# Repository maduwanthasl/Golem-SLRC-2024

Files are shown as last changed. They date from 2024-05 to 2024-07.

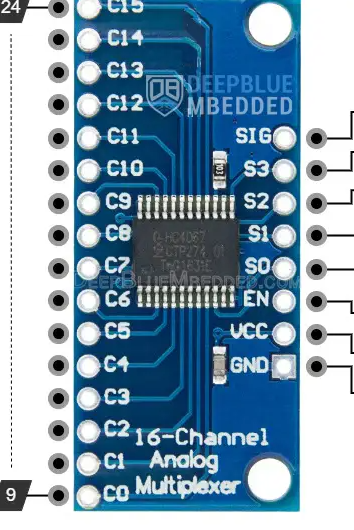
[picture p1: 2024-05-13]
SLRC shield/DOCS/Screenshot 2024-04-01 222949.png

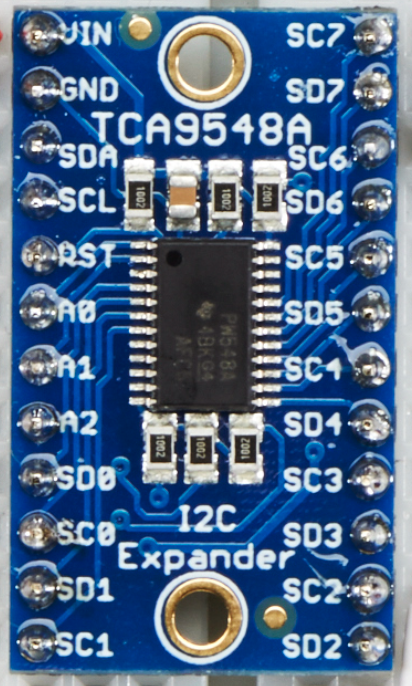
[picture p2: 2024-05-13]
SLRC shield/DOCS/Screenshot 2024-04-01 223036.png

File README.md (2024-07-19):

# Golem - SLRC 2024

Welcome to the Golem-SLRC-2024 repository! This project showcases my participation in the Sri Lanka Robotic Challenge (SLRC) 2024, organized by the Electronic Club at the University of Moratuwa. I participated as an individual team member and successfully completed the elimination round, securing a place in the final round. This repository contains the final code, design files, and documentation for my robot, Golem.

task

## Project Overview

Golem is a line-following robot designed to navigate complex paths and perform various tasks autonomously. The robot was built using an Arduino Mega board, various sensors, motor drivers, and custom-designed components. A notable feature of Golem is its robotic arm, which I designed and 3D printed using my Imagineer 3D printer. This document provides a detailed overview of the project's development, including the design, implementation, and functionality of Golem.

## Table of Contents
- [Project Overview](#project-overview)
- [Hardware Components](#hardware-components)
- [Software Components](#software-components)
- [Robot Design](#robot-design)
- [Functionality](#functionality)
- [Code Segments](#code-segments)
- [Photos](#photos)
- [Acknowledgements](#acknowledgements)

## Hardware Components

- Arduino Mega Board
- 14 IR Sensors Array
- L298N Motor Driver
- 12V LiPo Battery
- Buck Converters (LM2596)
- TOF Sensor (Time of Flight)
- OLED Display
- Rotary Encoder
- TCS34725 Color Sensor Module
- Ultrasonic Sensor
- MG995 Servo Motor
- Hobby Servo Motor
- Custom 3D Printed Parts (using Imagineer 3D Printer)
- Acrylic Sheets for Chassis

## Software Components

The software for Golem was developed using Arduino IDE, and the code is organized into several sub-functions to handle different tasks:

- Forward Line Following
- Reverse Line Following
- IR Sensor Calibration
- EEPROM Read/Write
- TOF Distance Measurement
- Color Detection
- Object Detection
- Robotic Arm Control

## Robot Design

In the initial stage, I constructed the robot chassis using acrylic sheets and purchased various components. The design process involved categorizing all functions into sub-functions and developing them within a specified time frame.

### Sub-Tasks

1. **Forward Line Following**: Using a 14 IR sensor array to follow lines.
2. **Distance Measurement**: Adding a TOF sensor to measure distance.
3. **Function Control**: Using an OLED display and rotary encoder to control functions.
4. **IR Sensor Calibration**: Developing calibration code for the IR arrays.
5. **Reverse Line Following**: Adding a reverse IR array for reverse functions and junction detection.
6. **EEPROM Storage**: Implementing EEPROM read/write functions for calibration values.
7. **Color Detection**: Using a TCS34725 color sensor module for junction color detection.
8. **Object Detection**: Adding an ultrasonic sensor for object detection and differentiation between cuboid and cylinder.
9. **Robotic Arm**: Constructing a simple 2-DOF robotic arm to pick up metal boxes.

## Functionality

## Software Components

The software for Golem was developed in a modular approach, where each functionality was divided into sub-functions and implemented step-by-step. The key functionalities include:

### 1. Forward Line Following using 14 IR Sensors

I used 14 IR sensors to develop the line-following task. The IR sensors detect the path, and the robot adjusts its movement accordingly using the L298N motor driver. The 12V LiPo battery provides the necessary power, and buck converters (LM2596) ensure stable voltage for the components.

#### Sensor calibration
```cpp
#include "calibrate_sensor.h"

/*-----------------------------------------------------------------------------------------------------------
----------------------------------------------SENSOR CALIBRATION---------------------------------------------
-----------------------------------------------------------------------------------------------------------*/

// Function to save threshold values to EEPROM
void saveThresholdToEEPROM() {
  int address = 0; // Starting EEPROM address to write the data

  // Write threshold values to EEPROM
  for (int i = 0; i < numSensors; i++) {
    EEPROM.put(address, threshold[i]); // Write threshold value to EEPROM
    address += sizeof(int); // Increment address for next threshold value
  }

}

// Function to read threshold values from EEPROM
void readThresholdFromEEPROM() {
  int address = 0; // Starting EEPROM address to read the data

  // Read threshold values from EEPROM
  for (int i = 0; i < numSensors ; i++) {
    EEPROM.get(address, threshold[i]); // Read threshold value from EEPROM
    address += sizeof(int); // Increment address for next threshold value
  }
}

void calibrateSensors() {
  Serial.println("Calibrating sensors...");
  
  // Initialize minValues and maxValues arrays
  for (int i = 0; i < numSensors; i++) {
    minValues[i] = 1023; // Initialize with maximum possible value
    maxValues[i] = 0; // Initialize with minimum possible value
  }

  // Move motors to calibrate sensors
  for (int i = 0; i < 12000; i++) { // Adjust the loop count and motor speeds as needed
    analogWrite(leftmotor_pwm,105);
    analogWrite(rightmotor_pwm,105);
    digitalWrite(leftForward,HIGH);
    digitalWrite(rightBackward,HIGH);
    for (int sensorIndex = 0; sensorIndex < numSensors; sensorIndex++) {
      int sensorValue = analogRead(sensorPins[sensorIndex]);
      minValues[sensorIndex] = min(minValues[sensorIndex], sensorValue);
      maxValues[sensorIndex] = max(maxValues[sensorIndex], sensorValue);
    }
  }

  // Stop motors
  analogWrite(leftmotor_pwm,0);
  analogWrite(rightmotor_pwm,0);
  stop_bot();

  // Calculate thresholds
  for (int i = 0; i < numSensors; i++) {
    threshold[i] = (minValues[i] + maxValues[i]) / 2;
  }

  // // Print thresholds
  // Serial.println("Sensor thresholds:");
  // for (int i = 0; i < numSensors; i++) {
  //   Serial.print("Sensor ");
  //   Serial.print(i + 1);
  //   Serial.print(": ");
  //   Serial.println(threshold[i]);
  // }
  // Serial.println("Calibration complete.");

}

/*------------------------------------------------------------------------------------------------------------
--------------------------------------------------------------------------------------------------------------
------------------------------------------------------------------------------------------------------------*/

// Function to save threshold values to EEPROM for reverse sensors
void saveThresholdToEEPROMreverse() {
  int address = 0; // Starting EEPROM address to write the data

  // Write threshold values to EEPROM
  for (int i = 0; i < numReverseSensors; i++) {
    EEPROM.put(address, reverseThreshold[i]); // Write threshold value to EEPROM
    address += sizeof(int); // Increment address for next threshold value
  }
}

// Function to read threshold values from EEPROM for reverse sensors
void readThresholdFromEEPROMreverse() {
  int address = 0; // Starting EEPROM address to read the data

  // Read threshold values from EEPROM
  for (int i = 0; i < numReverseSensors ; i++) {
    EEPROM.get(address, reverseThreshold[i]); // Read threshold value from EEPROM
    address += sizeof(int); // Increment address for next threshold value
  }
}

void calibrateReverseSensors() {
  Serial.println("Calibrating reverse sensors...");
  
  // Initialize minValues and maxValues arrays
  for (int i = 0; i < numReverseSensors; i++) {
    reverseMinValues[i] = 1023; // Initialize with maximum possible value
    reverseMaxValues[i] = 0; // Initialize with minimum possible value
  }

  // Move motors to calibrate sensors
  for (int i = 0; i < 12000; i++) { // Adjust the loop count and motor speeds as needed
    analogWrite(leftmotor_pwm, 105);
    analogWrite(rightmotor_pwm, 105);
    digitalWrite(leftBackward, HIGH); // Assuming reverse array needs to move backward
    digitalWrite(rightForward, HIGH); // Assuming reverse array needs to move backward
    for (int sensorIndex = 0; sensorIndex < numReverseSensors; sensorIndex++) {
      // Select the channel on the multiplexer
      selectChannel(sensorIndex);

      // Read the sensor value from the multiplexer
      int sensorValue = analogRead(reverseSensorPins[sensorIndex]);

      // Update min and max values
      reverseMinValues[sensorIndex] = min(reverseMinValues[sensorIndex], sensorValue);
      reverseMaxValues[sensorIndex] = max(reverseMaxValues[sensorIndex], sensorValue);
    }
  }

  // Stop motors
  analogWrite(leftmotor_pwm, 0);
  analogWrite(rightmotor_pwm, 0);
  stop_bot();

  // Calculate thresholds
  for (int i = 0; i < numReverseSensors; i++) {
    reverseThreshold[i] = (reverseMinValues[i] + reverseMaxValues[i]) / 2;
  }

  Serial.println("Reverse sensor thresholds:");
  for (int i = 0; i < numReverseSensors; i++) {
    Serial.print("Sensor ");
    Serial.print(i + 1);
    Serial.print(": ");
    Serial.println(reverseThreshold[i]);
  }
  Serial.println("Reverse Calibration complete.");
}
```

```cpp
void read_sensor_values()
{
  readThresholdFromEEPROM();
  // White == 1 & Black == 0 left - , right +
  for (int sensorIndex = 0; sensorIndex < numSensors; sensorIndex++) {
    sensorValues[sensorIndex] = analogRead(sensorPins[sensorIndex]);
    if (sensorValues[sensorIndex] > threshold[sensorIndex]) {
        sensorValues[sensorIndex] = 0;
    } else {
        sensorValues[sensorIndex] = 1;
    }
  }

  int expectedValues[][numSensors] = {
    // Add your expected values here
  };

  int errorValues[] = {
    // Add your error values here
  };

  bool conditionMet = false;
  int defaultErrorValue = 0;

  for (int condIndex = 0; condIndex < sizeof(expectedValues) / sizeof(expectedValues[0]); condIndex++) {
    conditionMet = true;
    for (int sensorIndex = 0; sensorIndex < numSensors; sensorIndex++) {
      if (expectedValues[condIndex][sensorIndex] != -1 && sensorValues[sensorIndex] != expectedValues[condIndex][sensorIndex]) {
        conditionMet = false;
        break;
      }
    }
    if (conditionMet) {
      error = errorValues[condIndex];
      if (condIndex >= sizeof(errorValues) / sizeof(errorValues[0]) - 13) {
        motor_pos = 0; motor_pos2 = 0;
        count_encoder(0.45);
        junction_count++;
        motor_pos = 0; motor_pos2 = 0;
        Serial.println(junction_count);
      }
      break;
    }
  }

  if (!conditionMet) {
    error = defaultErrorValue;
  }
}
```

### 2. TOF Sensor Integration for Distance Measurement

A Time of Flight (TOF) sensor was added to measure the distance accurately. This helps the robot navigate and avoid obstacles.

```cpp
#include "measure_distance_tof.h"

static Adafruit_VL53L0X lox = Adafruit_VL53L0X();

void measure_distance_tof_setup() {
  Serial.begin(9600);

  // Wait until serial port opens for native USB devices
  while (!Serial) {
    delay(1);
  }

  Serial.println("Adafruit VL53L0X test");
  if (!lox.begin()) {
    Serial.println(F("Failed to boot VL53L0X"));
    while(1);
  }
  // Power 
  Serial.println(F("VL53L0X API Simple Ranging example\n\n"));
}

void measure_distance_tof_loop(int Samples) {
  VL53L0X_RangingMeasurementData_t measure;
  unsigned long totalDistance = 0; // Variable to store the total distance
  int numSamples = Samples ; // Number of samples to average

  for (int i = 0; i < numSamples; i++) {
    lox.rangingTest(&measure, false); // Perform distance measurement
    if (measure.RangeStatus != 4) {  // Phase failures have incorrect data
      totalDistance += measure.RangeMilliMeter; // Add the distance measurement to the total
    }
    delay(50); // Wait a short time between measurements
  }

  // Compute the average distance
  distance_tof = totalDistance / numSamples;

  Serial.print("Average Distance (mm): ");
  Serial.println(distance_tof);
  return;

}
```

### 3. OLED Display and Rotary Encoder for Control

An OLED display was added to provide real-time information about the robot's status. The rotary encoder allows for easy navigation through different functions and settings on the display, making the robot more user-friendly.

### 4. IR Array Calibration

Calibration code for the IR arrays was developed to ensure accurate line following. Here is a sample of the calibration code:

### 5. Reverse Function and Junction Detection
A reverse IR array was added to enable the robot to move backward and detect junctions. Calibration code was also implemented for the reverse sensors. The calibrated values are stored in the EEPROM for quick access.

### 6. EEPROM Read and Write
I developed code to read and write calibration values to the EEPROM. This ensures that the robot retains its calibration settings even after power cycles.

### 7. Color Detection using TCS34725
A TCS34725 color sensor module was mounted below the robot to detect color junctions on the path. This sensor helps the robot identify different colored markers on the track.

### 8. Ultrasonic Sensor for Object Detection
An ultrasonic sensor was used to detect objects within a circle. The sensor measures the distance and helps identify whether the object is a cuboid or a cylinder based on the variance in the measurements.

### 9. Robotic Arm with 2 DOF
I designed a simple robotic arm with two degrees of freedom (DOF) to pick up objects. The arm uses an MG995 servo motor and a hobby servo motor. The arm design was created using CAD software and 3D printed using my Imagineer 3D printer.

## Code Segments
Here are some key code segments used in the project:

### IR Sensor Calibration
```cpp
void calibrateSensors() {
    // Calibration logic
}
```

### EEPROM Read and Write
```cpp
void saveThresholdToEEPROM() {
    // Code to save calibration values to EEPROM
}

void readThresholdFromEEPROM() {
    // Code to read calibration values from EEPROM
}
```
### Color Detection
```cpp
void detectColor() {
    // Code to detect colors using TCS34725 sensor
}
```
### Ultrasonic Object Detection
```cpp

void detectObject() {
    // Code to detect objects using ultrasonic sensor
}
```
## Photos
Robot Photos: Link to Photos
Task Photos: Link to Photos
Elimination Round Photos: Link to Photos

## Acknowledgements
I would like to thank the Electronic Club at the University of Moratuwa for organizing the Sri Lanka Robotic Challenge (SLRC) 2024. Special thanks to my mentors and peers for their support and guidance throughout the project.

Contact
For any questions or collaborations, feel free to reach out to me at [Your Email].

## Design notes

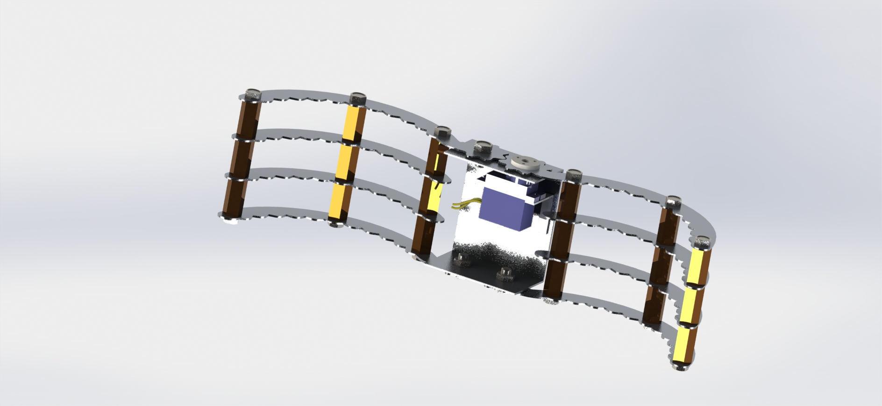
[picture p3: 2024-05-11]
3d printed parts/robot-claw-robot-gripper-gripper-manipulator-mechanical-claw-arm-1.snapshot.3/f3.JPG

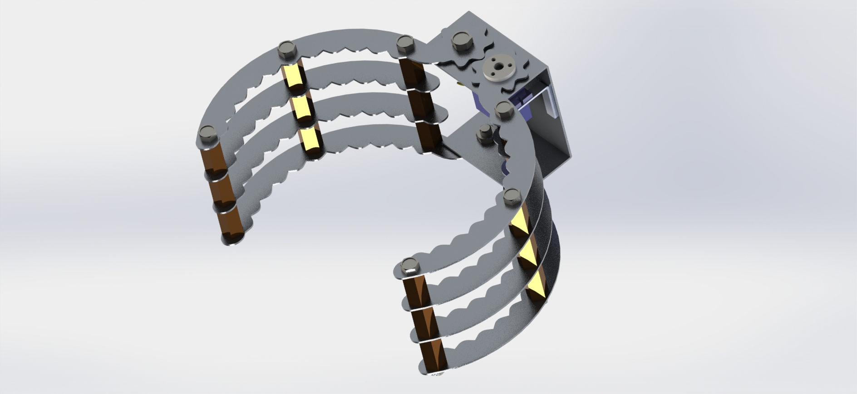
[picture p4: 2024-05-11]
3d printed parts/robot-claw-robot-gripper-gripper-manipulator-mechanical-claw-arm-1.snapshot.3/f2.JPG

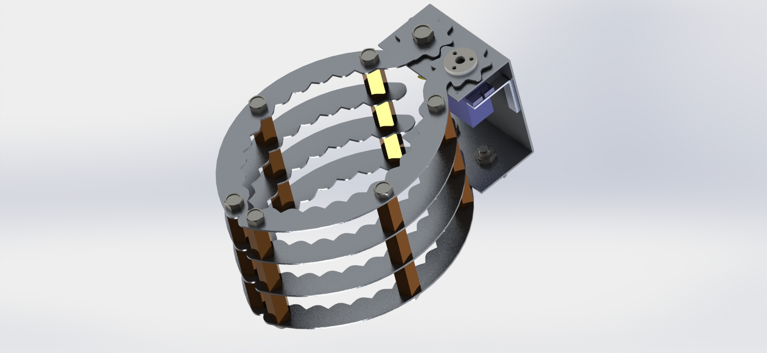
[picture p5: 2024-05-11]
3d printed parts/robot-claw-robot-gripper-gripper-manipulator-mechanical-claw-arm-1.snapshot.3/f1.JPG

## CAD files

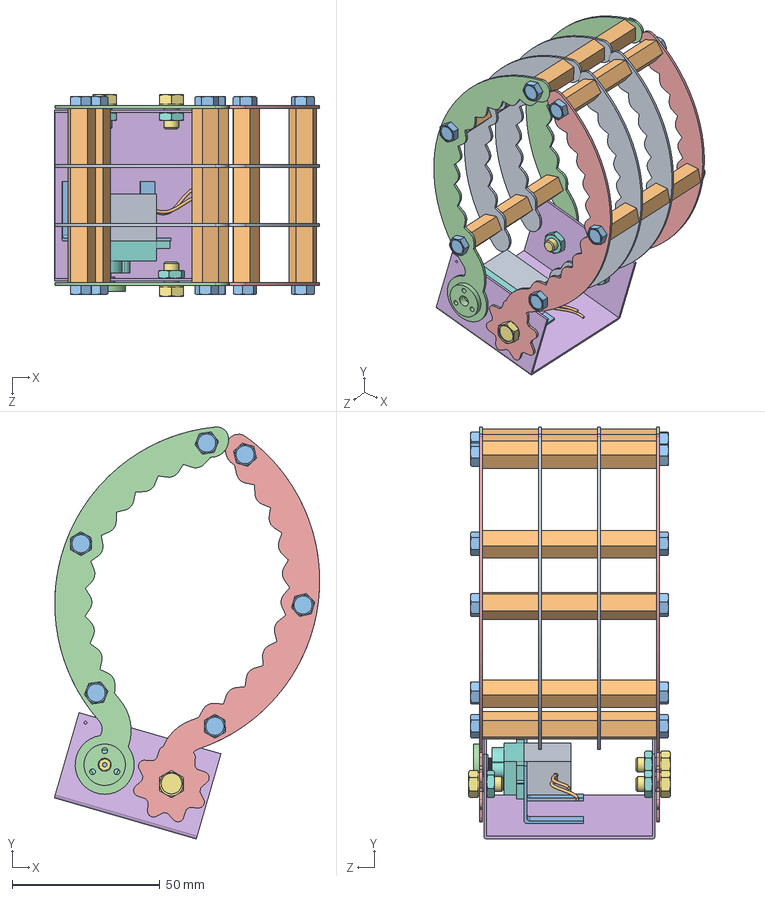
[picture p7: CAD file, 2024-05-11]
3d printed parts/robot-claw-robot-gripper-gripper-manipulator-mechanical-claw-arm-1.snapshot.3/oval-kiskac.SLDASM
89.8 x 139.4 x 68.3 mm
kiskac2 x 4
araparca x 18
hex screw_am x 12
kiskac1 x 2
kiskac1-sol x 2
U-sac
formed hex screw_am x 3
hex nut jam_am x 3
lower cover
motor
feedback potentiometer
Part6^servo motor assembley
Part7^servo motor assembley
Part8^servo motor assembley
Part10^servo motor assembley
upper cover
Part16^servo motor assembley
Part21^servo motor assembley
20x20x1kosebent x 2
dondurme-aparati

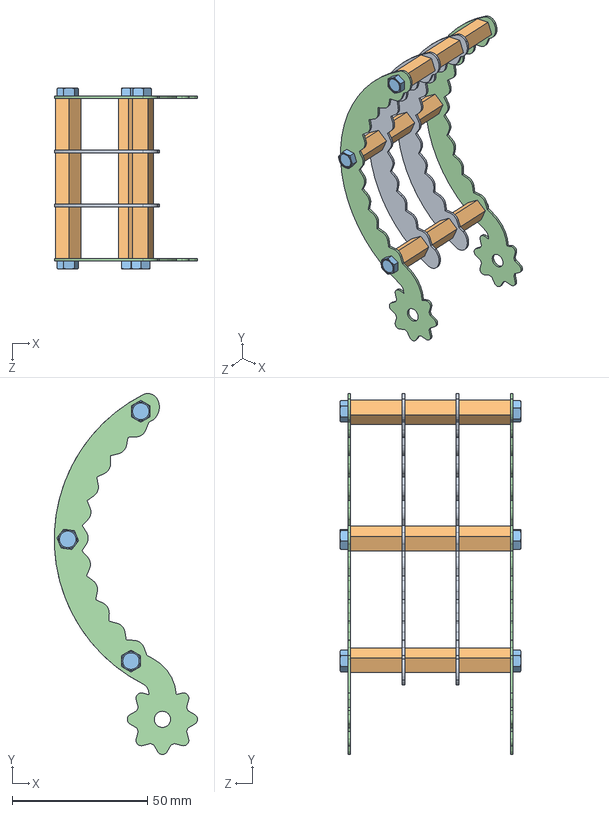
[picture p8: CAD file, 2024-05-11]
3d printed parts/robot-claw-robot-gripper-gripper-manipulator-mechanical-claw-arm-1.snapshot.3/kıskac2-montaj.SLDASM
52.9 x 133.5 x 67.0 mm
kiskac2 x 2
araparca x 9
hex screw_am x 6
kiskac1 x 2

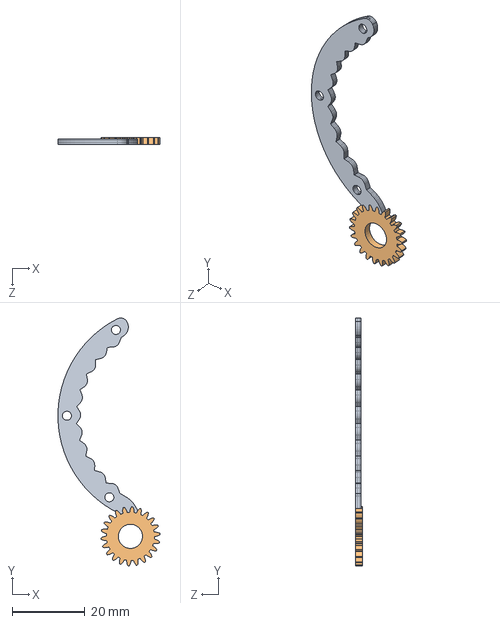
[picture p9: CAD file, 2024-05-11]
3d printed parts/robot-claw-robot-gripper-gripper-manipulator-mechanical-claw-arm-1.snapshot.3/dfsgd.SLDASM
28.1 x 68.4 x 1.82 mm
kiskac1 x 3
gear

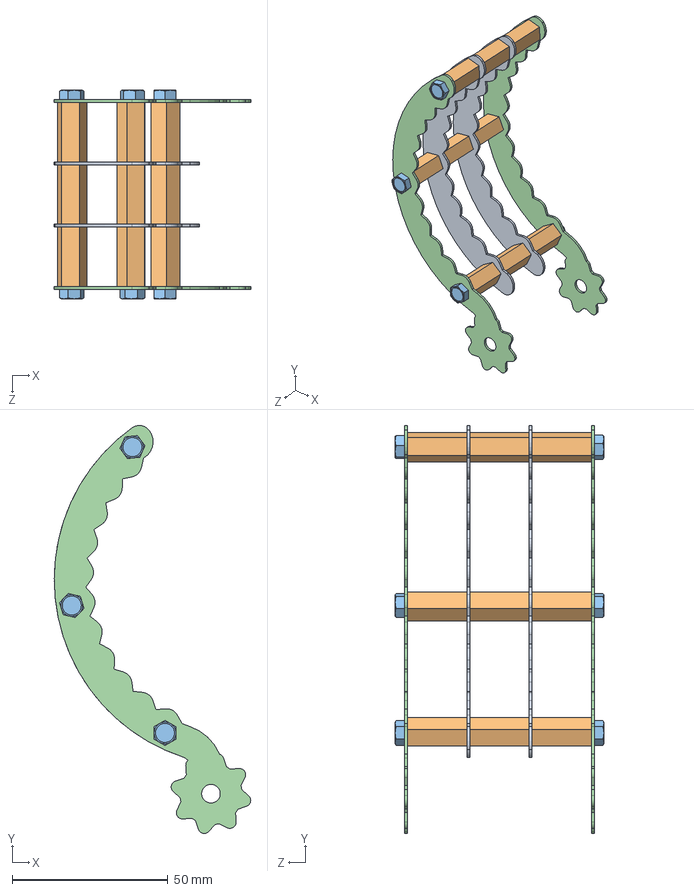
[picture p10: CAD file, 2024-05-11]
3d printed parts/robot-claw-robot-gripper-gripper-manipulator-mechanical-claw-arm-1.snapshot.3/kıskac1-montaj.SLDASM
63.1 x 131.1 x 67.0 mm
kiskac2 x 2
araparca x 9
hex screw_am x 6
kiskac1-sol x 2

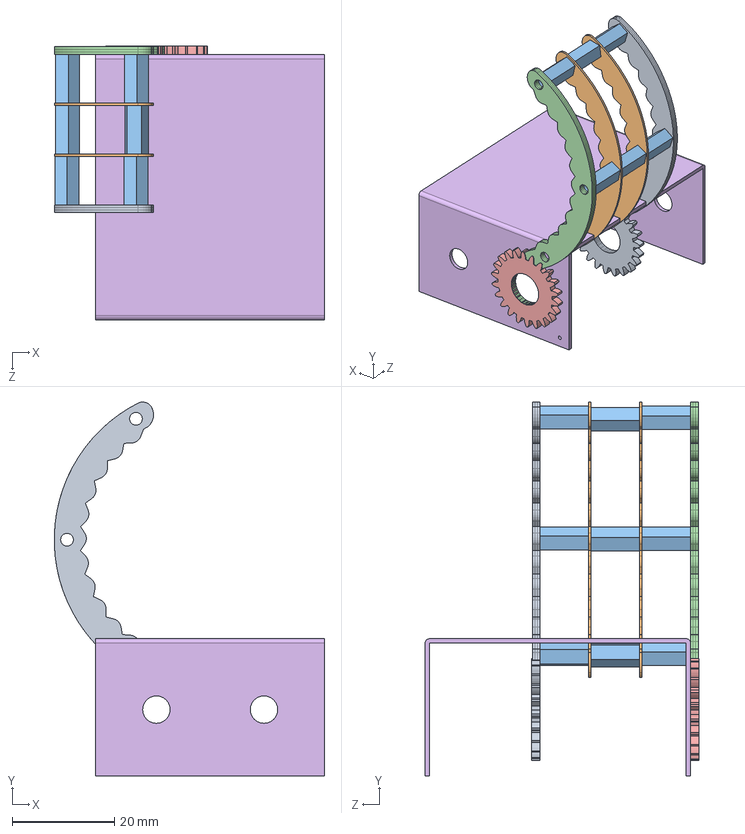
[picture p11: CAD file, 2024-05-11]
3d printed parts/robot-claw-robot-gripper-gripper-manipulator-mechanical-claw-arm-1.snapshot.3/RIGHT HAND.SLDASM
52.9 x 73.2 x 53.6 mm
handle1
kiskac2 x 2
araparca x 9
kiskac1 x 3
gear
U-sac

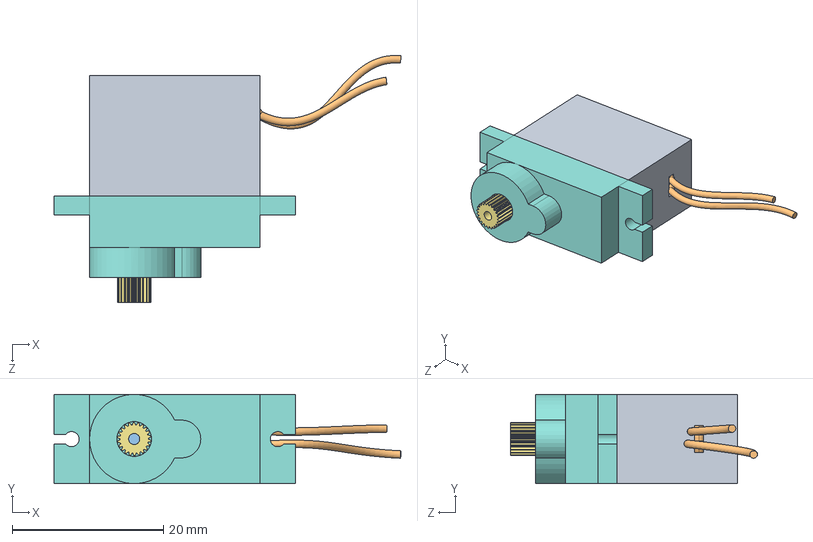
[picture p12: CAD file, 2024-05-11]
3d printed parts/robot-claw-robot-gripper-gripper-manipulator-mechanical-claw-arm-1.snapshot.3/servo-motor-montaj.SLDASM
45.9 x 11.8 x 32.7 mm
lower cover
motor
feedback potentiometer
Part6^servo motor assembley
Part7^servo motor assembley
Part8^servo motor assembley
Part10^servo motor assembley
upper cover
Part16^servo motor assembley
Part21^servo motor assembley

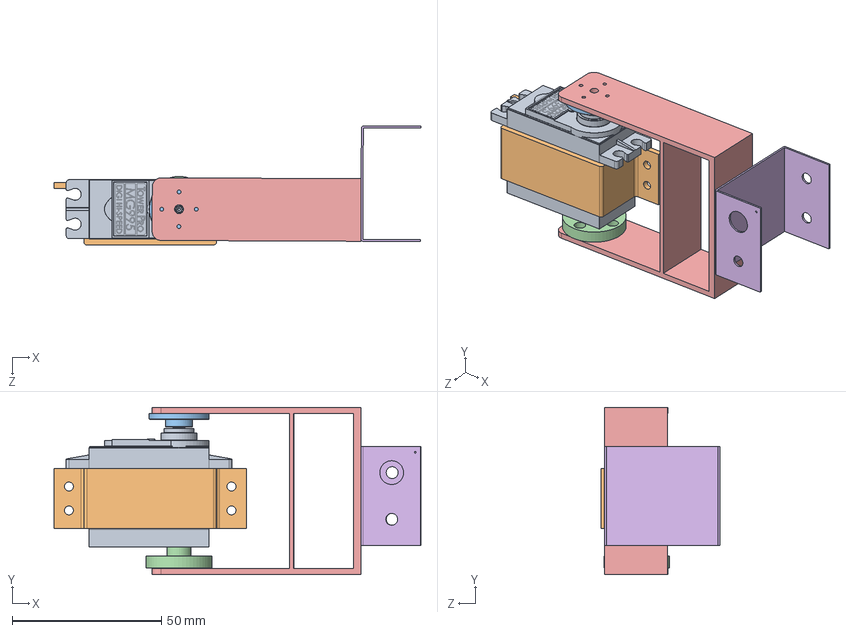
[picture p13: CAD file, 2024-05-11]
3d printed parts/Arm assemble.SLDASM
123.0 x 56.0 x 39.9 mm
Mg995
Servo holder
servo horn
hub
Arm handle
U-sac

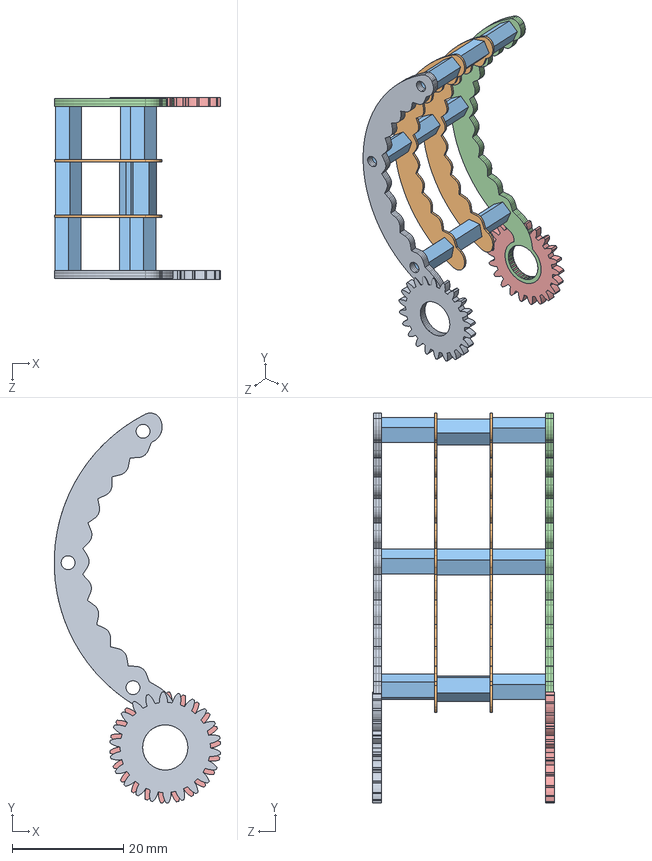
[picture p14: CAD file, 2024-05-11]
3d printed parts/robot-claw-robot-gripper-gripper-manipulator-mechanical-claw-arm-1.snapshot.3/Assem2.SLDASM
30.0 x 70.2 x 32.8 mm
handle1
kiskac2 x 2
araparca x 9
kiskac1 x 3
gear

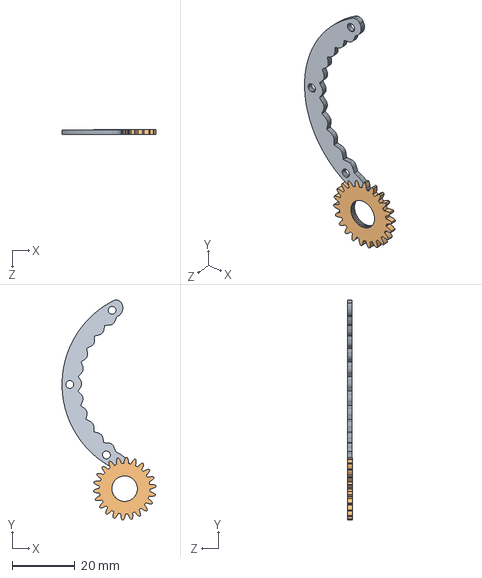
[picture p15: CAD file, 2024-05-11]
3d printed parts/robot-claw-robot-gripper-gripper-manipulator-mechanical-claw-arm-1.snapshot.3/handle 2.SLDASM
30.0 x 70.2 x 1.63 mm
kiskac1 x 3
gear

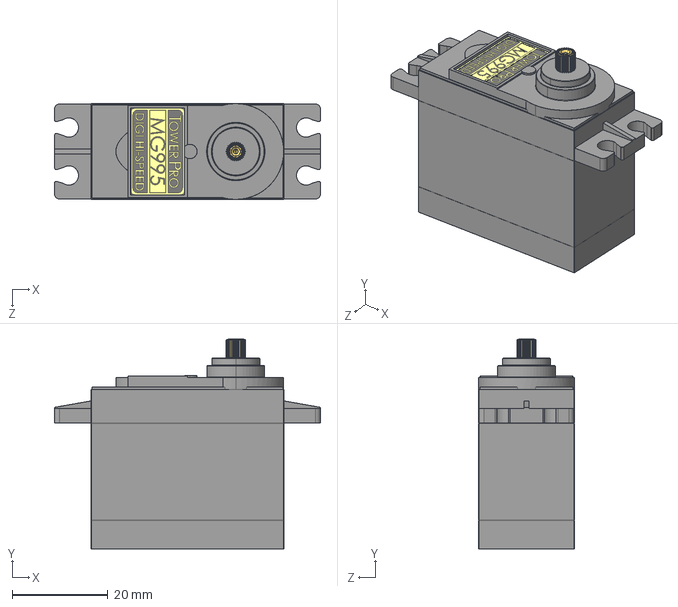
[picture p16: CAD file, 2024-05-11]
3d printed parts/mg-995-2.snapshot.2/Mg995.STEP
55.5 x 43.8 x 20.0 mm

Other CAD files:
3d printed parts/robot-claw-robot-gripper-gripper-manipulator-mechanical-claw-arm-1.snapshot.3/Part8^servo motor assembley.sldprt
3d printed parts/robot-claw-robot-gripper-gripper-manipulator-mechanical-claw-arm-1.snapshot.3/Part16^servo motor assembley.sldprt
3d printed parts/robot-claw-robot-gripper-gripper-manipulator-mechanical-claw-arm-1.snapshot.3/Part7^servo motor assembley.sldprt
3d printed parts/robot-claw-robot-gripper-gripper-manipulator-mechanical-claw-arm-1.snapshot.3/Part14^servo motor assembley.sldprt
3d printed parts/robot-claw-robot-gripper-gripper-manipulator-mechanical-claw-arm-1.snapshot.3/Part6^servo motor assembley.sldprt
3d printed parts/robot-claw-robot-gripper-gripper-manipulator-mechanical-claw-arm-1.snapshot.3/Part10^servo motor assembley.sldprt
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

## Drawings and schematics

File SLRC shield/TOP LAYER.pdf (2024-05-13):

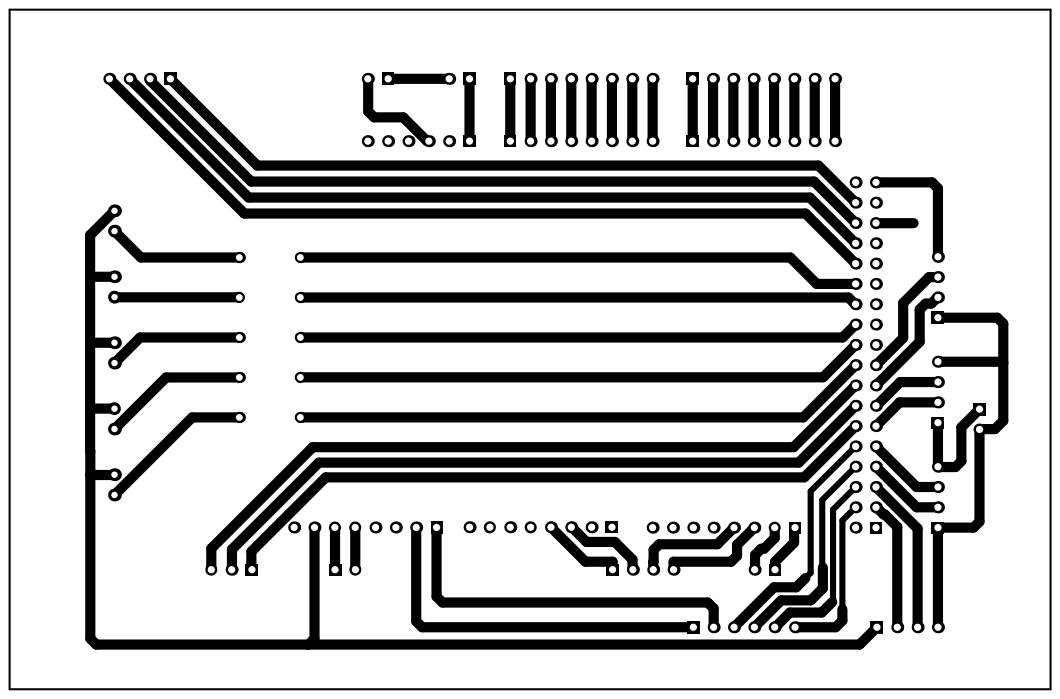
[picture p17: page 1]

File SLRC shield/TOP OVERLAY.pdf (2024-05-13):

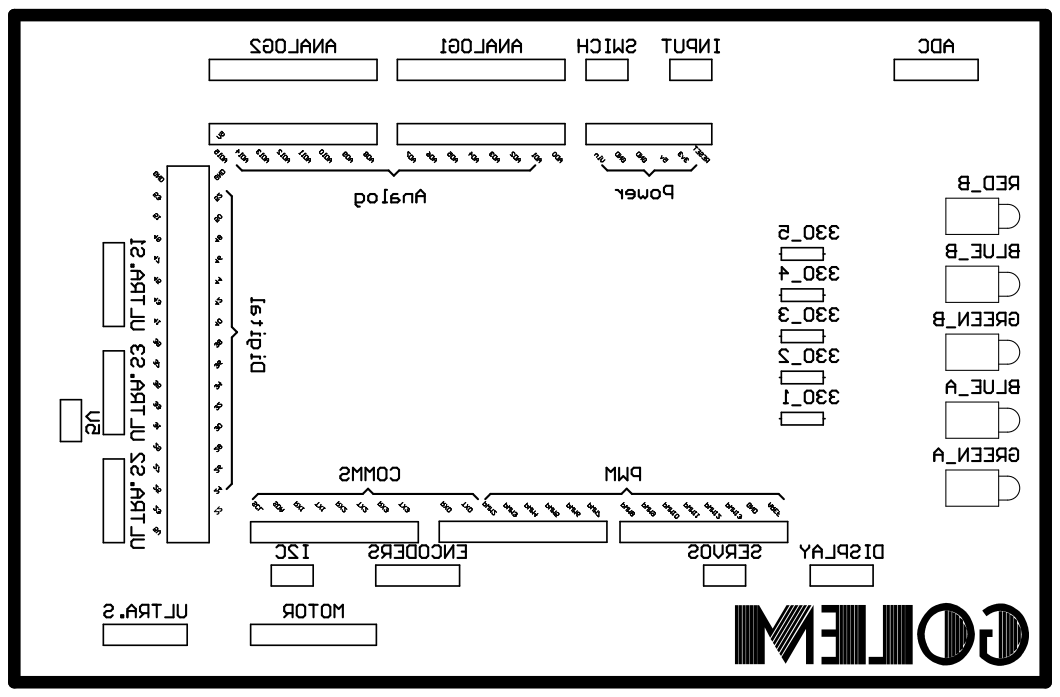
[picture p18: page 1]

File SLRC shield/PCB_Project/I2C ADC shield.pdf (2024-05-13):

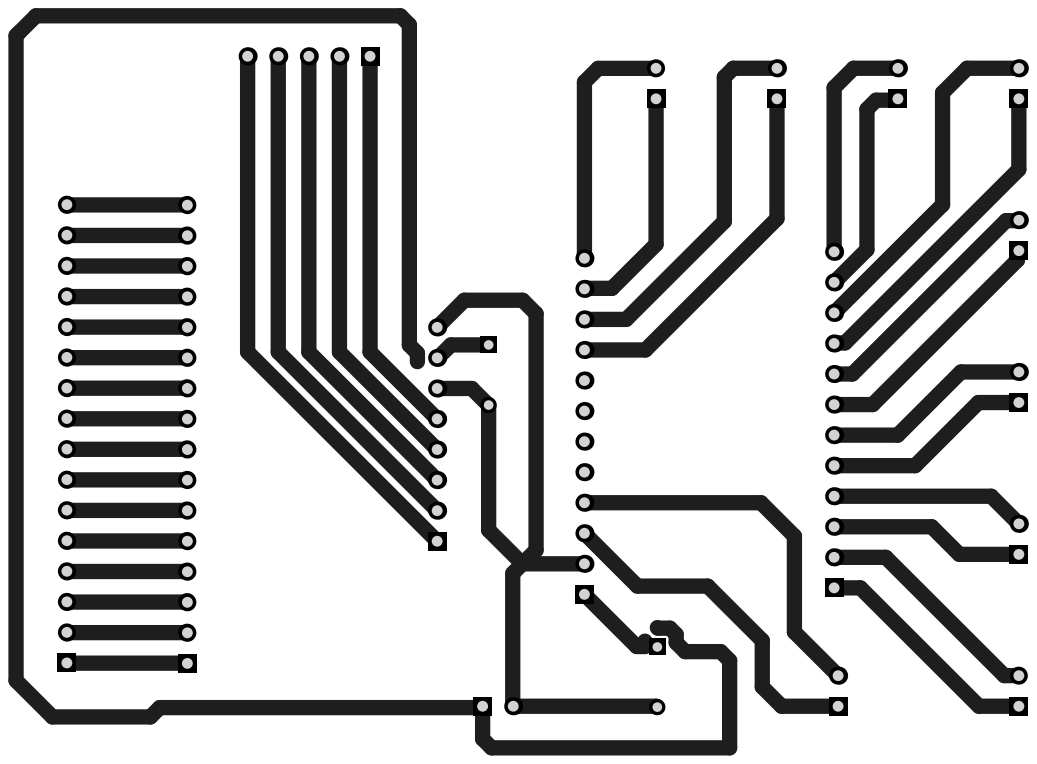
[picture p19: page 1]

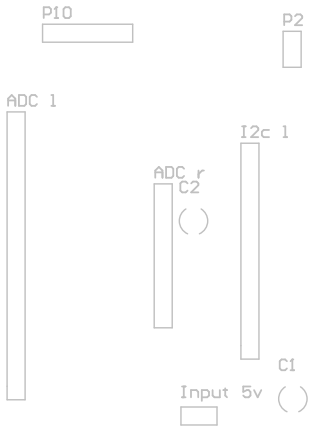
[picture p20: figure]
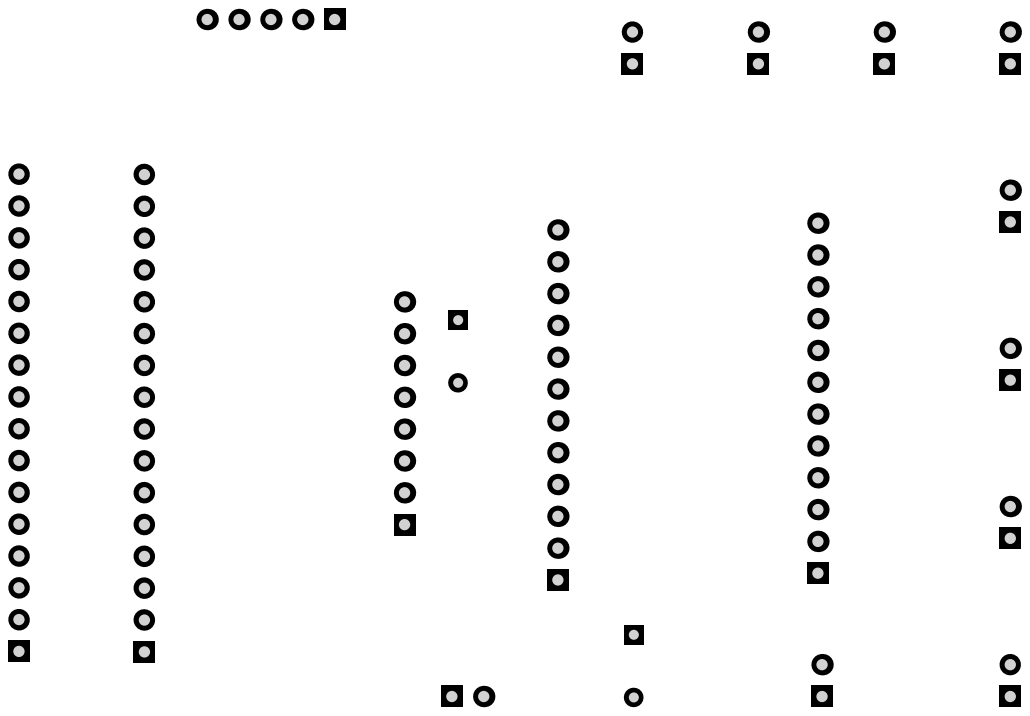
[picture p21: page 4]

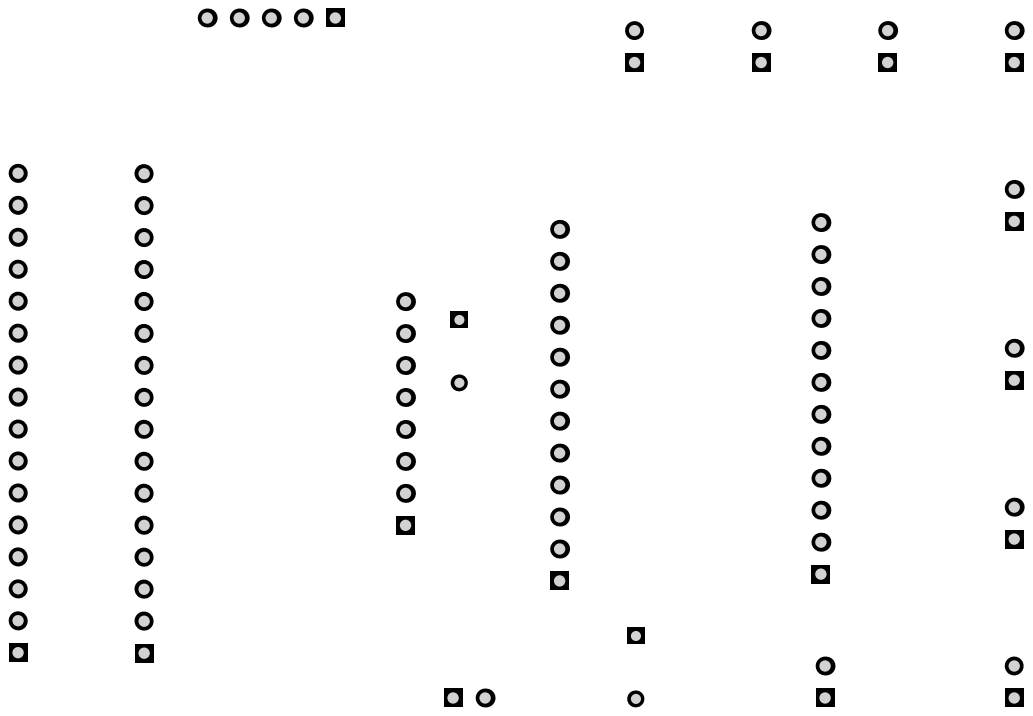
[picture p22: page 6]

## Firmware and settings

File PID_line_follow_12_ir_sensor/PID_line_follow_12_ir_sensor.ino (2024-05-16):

//Define motor pins
#define leftmotor_pwm 9
#define rightmotor_pwm 8
#define leftForward 26
#define rightForward 22
#define leftBackward 28
#define rightBackward 24

//define ir array sensors and calibration arrays and pins
const int numSensors = 12; // Number of IR sensors
const int sensorPins[numSensors] = {A7,A6,A15, A14, A13, A12, A11, A10, A9, A8,A5,A4}; // Sensor pin numbers
int sensorValues[numSensors]; // Array to store sensor values
int minValues[numSensors]; // Array to store minimum sensor values
int maxValues[numSensors]; // Array to store maximum sensor values
int threshold[numSensors]; // Array to store sensor thresholds   


//Initial Speed of Motor
int initial_motor_speed = 40;

// PID Constants
float Kp = 4;//18
float Ki = 1;//6
float Kd = 0;//8

float error = 0, P = 0, I = 0, D = 0, PID_value = 0;
float previous_error = 0, previous_I = 0;

int flag = 0;

void setup()
{

  pinMode(leftForward, OUTPUT);
  pinMode(leftBackward, OUTPUT);
  pinMode(rightForward, OUTPUT);
  pinMode(rightBackward, OUTPUT);
  pinMode(leftmotor_pwm, OUTPUT); // Changed from ENA
  pinMode(rightmotor_pwm, OUTPUT); // Changed from ENB

  Serial.begin(9600);                     //setting serial monitor at a default baund rate of 9600
  delay(5000);

  calibrateSensors(); // Calibrate the sensors
  delay(5000);

  Serial.println("Started !!");
  delay(1000);
}


/*-----------------------------------------------------------------------------------------------------------
----------------------------------------------SENSOR CALIBRATION---------------------------------------------
-----------------------------------------------------------------------------------------------------------*/

void calibrateSensors() {
  Serial.println("Calibrating sensors...");
  
  // Initialize minValues and maxValues arrays
  for (int i = 0; i < numSensors; i++) {
    minValues[i] = 1023; // Initialize with maximum possible value
    maxValues[i] = 0; // Initialize with minimum possible value
  }

  // Move motors to calibrate sensors
  for (int i = 0; i < 12000; i++) { // Adjust the loop count and motor speeds as needed
    analogWrite(leftmotor_pwm,45);
    analogWrite(rightmotor_pwm,45);
    digitalWrite(leftForward,HIGH);
    digitalWrite(rightBackward,HIGH);
    
    

    for (int sensorIndex = 0; sensorIndex < numSensors; sensorIndex++) {
      int sensorValue = analogRead(sensorPins[sensorIndex]);
      minValues[sensorIndex] = min(minValues[sensorIndex], sensorValue);
      maxValues[sensorIndex] = max(maxValues[sensorIndex], sensorValue);
    }
  }

  // Stop motors
  analogWrite(leftmotor_pwm*200/78,0);
  analogWrite(rightmotor_pwm,0);
  stop_bot();


  // Calculate thresholds
  for (int i = 0; i < numSensors; i++) {
    threshold[i] = (minValues[i] + maxValues[i]) / 2;
  }

  // Print thresholds
  Serial.println("Sensor thresholds:");
  for (int i = 0; i < numSensors; i++) {
    Serial.print("Sensor ");
    Serial.print(i + 1);
    Serial.print(": ");
    Serial.println(threshold[i]);
  }

  Serial.println("Calibration complete.");
}

/*------------------------------------------------------------------------------------------------------------
--------------------------------------------------------------------------------------------------------------
------------------------------------------------------------------------------------------------------------*/


void loop()
{
  read_sensor_values();

  if (error == 100) {               // Make left turn untill it detects straight path
    do {
      read_sensor_values();
      analogWrite(leftmotor_pwm, 70); //Changed from ENA
      analogWrite(rightmotor_pwm, 70); //Changed from ENB
      sharpLeftTurn();
      // Serial.println("error == 100");
    } while (error != 0 && error != -1 && error != 1);

  } 
  else if (error == 101) {          // Make right turn in case of it detects only right path (it will go into forward direction in case of staright and right "|--")
                                      // untill it detects straight path.
    analogWrite(leftmotor_pwm, 70); //Changed from ENA
    analogWrite(rightmotor_pwm, 70); //Changed from ENB
    forward();
    delay(150);
    stop_bot();
    read_sensor_values();
    if (error == 102) {
      do {
        analogWrite(leftmotor_pwm, 70); //Changed from ENA
        analogWrite(rightmotor_pwm, 70); //Changed from ENB
        sharpRightTurn();
        read_sensor_values();
      } while (error != 0 && error != -1 && error != 1);
    }
  } 
  else if (error == 102) {        // Make left turn untill it detects straight path
    do {
      analogWrite(leftmotor_pwm, 70); //Changed from ENA
      analogWrite(rightmotor_pwm, 70); //Changed from ENB
      sharpLeftTurn();
      read_sensor_values();
      if (error == 0 || error == 1 || error == -1) {
        stop_bot();
        delay(200);
      }
    }  while (error != 0 && error != -1 && error != 1);
  } 
  else if (error == 103) { // Make left turn untill it detects straight path or stop if dead end reached.
    if (flag == 0) {
      analogWrite(leftmotor_pwm, 70); //Changed from ENA
      analogWrite(rightmotor_pwm, 70); //Changed from ENB
      forward();
      delay(200);
      stop_bot();
      read_sensor_values();
      if (error == 103) {     /**** Dead End Reached, Stop! ****/
        stop_bot();
        flag = 1;
      } else {        /**** Move Left ****/
        analogWrite(leftmotor_pwm, 70); //Changed from ENA
        analogWrite(rightmotor_pwm, 70); //Changed from ENB
        sharpLeftTurn();
        delay(200);
        do {
          read_sensor_values();
          analogWrite(leftmotor_pwm, 70); //Changed from ENA
          analogWrite(rightmotor_pwm, 70); //Changed from ENB
          sharpLeftTurn();
        } while (error != 0 && error != -1 && error != 1);
      }
    }
  } 
  else {
    calculate_pid();
    motor_control();
  }
}


void read_sensor_values()
{
  //White == 1 & Black == 0 left - , right +
  for (int sensorIndex = 0; sensorIndex < numSensors; sensorIndex++) {
    sensorValues[sensorIndex] = analogRead(sensorPins[sensorIndex]);
    if (sensorValues[sensorIndex] > threshold[sensorIndex]) {
        sensorValues[sensorIndex] = 0;
    } else {
        sensorValues[sensorIndex] = 1;
    }
  }

  //print the values or the sensorVales array
  for (int i = 0; i < numSensors; i++) {
    Serial.print(sensorValues[i]);
    Serial.print(" ");
  }
  

  // Define all expected values in a single array
  int expectedValues[][numSensors] = {
    {0, 0, 0, 0, -1, -1, -1, -1, 0, 0, 0, 0},
    {0, 0, 0, 1, -1, -1, -1, -1, 1, 0, 0, 0},
    {0, 0, 0, 1, -1, -1, -1, 1, 0, 0, 0, 0},
    {0, 0, 0, 0, 1, -1, -1, -1, 1, 0, 0, 0},
    {0, 0, 0, 1, -1, -1, 1, 0, 0, 0, 0, 0},
    {0, 0, 1, -1, -1, -1, -1, 1, 0, 0, 0, 0},
    {0, 0, 0, 0, 0, 1, -1, -1, 1, 0, 0, 0},
    {0, 0, 0, 0, 1, -1, -1, -1, -1, 1, 0, 0},
    {0, 0, 1, -1, -1, -1, 1, 0, 0, 0, 0, 0},
    {0, 0, 0, 0, 0, 1, -1, -1, -1, 1, 0, 0},
    {0 ,0 ,0 ,0 ,0 ,0 ,1 ,-1 ,-1 ,-1 ,1 ,0 },
    {0 ,1 ,-1 ,-1 ,-1 ,1 ,0 ,0 ,0 ,0 ,0 ,0 },
    {0, 0, 1, -1, -1, 1, 0, 0, 0, 0, 0, 0},
    {0, 1, -1, -1, -1, -1, 1, 0, 0, 0, 0, 0},
    {0, 0, 0, 0, 0, 0, 1, -1, -1, 1, 0, 0},
    {0, 0, 0, 0, 0, 1, -1, -1, -1, -1, 1, 0},
    {0, 1, -1, -1, 1, 0, 0, 0, 0, 0, 0, 0},
    {0, 0, 0, 0, 0, 0, 0, 1, -1, -1, 1, 0},
    {0, 0, 0, 0, 0, 0, 0, 0, 1, -1, 1, 0},
    {0, 1, -1, 1, 0, 0, 0, 0, 0, 0, 0, 0},    
    {1, -1, -1, -1, 1, 0, 0, 0, 0, 0, 0, 0},
    {1, -1, -1, -1, -1, 1, 0, 0, 0, 0, 0, 0},
    {1, -1, -1, -1, -1, -1, 1, 0, 0, 0, 0, 0},
    {1, -1, -1, -1, -1, -1, -1, 1, 0, 0, 0, 0},
    {0, 0, 0, 0, 0, 0, 0, 1, -1, -1, -1, 1},
    {0, 0, 0, 0, 0, 0, 1, -1, -1, -1, -1, 1},
    {0, 0, 0, 0, 0, 1, -1, -1, -1, -1, -1, 1},
    {0, 0, 0, 0, 1, -1, -1, -1, -1, -1, -1, 1},
    {0, 0, 0, 0, 0, 0, 0, 0, 0, 0, 0, 0},
    {-1, -1, 1, 1, 1, 1, 1, 1, 1, 1, -1, -1}
  };


  // Define corresponding error values
  int errorValues[] = {0, 0, -1, 1, -2, -2, 2, 2, -3, +3,4,-4, -4, -4,4,4, -5,5,6,-6,100,100,100,100,101,101,101,101,102,103};

  // Initialize conditionMet as false
  bool conditionMet = false;

  int defaultErrorValue = 0;
  

  // Check if any condition is met
  for (int condIndex = 0; condIndex < sizeof(expectedValues) / sizeof(expectedValues[0]); condIndex++) {
    conditionMet = true; // Assume the condition is met initially
    for (int sensorIndex = 0; sensorIndex < numSensors; sensorIndex++) {
      if (expectedValues[condIndex][sensorIndex] != -1 && sensorValues[sensorIndex] != expectedValues[condIndex][sensorIndex]) {
        conditionMet = false; // Condition not met, break the inner loop
        break;
      }
    }
    if (conditionMet) {
      error = errorValues[condIndex]; // Set error based on the condition
      break; // Exit the loop if condition is met
    }
  }

  // If no condition is met, set error to default value
  if (!conditionMet) {
    error = defaultErrorValue;
  }

  Serial.print("    ");
  Serial.print(error);
  Serial.println();
  delay(1000);
}


void calculate_pid()
{
  P = error;
  I = I + previous_I;
  D = error - previous_error;

  PID_value = (Kp * P) + (Ki * I) + (Kd * D);

  previous_I = I;
  previous_error = error;
}

void motor_control()
{
  // Calculating the effective motor speed:
  int left_motor_speed = initial_motor_speed + PID_value;
  int right_motor_speed = initial_motor_speed - PID_value;

  // The motor speed should not exceed the max PWM value
  left_motor_speed = constrain(left_motor_speed, 0, 255);
  right_motor_speed = constrain(right_motor_speed, 0, 255);

  Serial.print(PID_value);
  Serial.print("\t");
  
  Serial.print(left_motor_speed);
  Serial.print("\t");
  Serial.println(right_motor_speed);
  delay(1000);


  

  analogWrite(leftmotor_pwm, left_motor_speed); //Left Motor Speed
  analogWrite(rightmotor_pwm, right_motor_speed); //Right Motor Speed

  //following lines of code are to make the bot move forward
  forward();
}


void forward()
{
  /*The pin numbers and high, low values might be different depending on your connections */
  digitalWrite(leftForward, HIGH);
  digitalWrite(leftBackward, LOW);
  digitalWrite(rightForward, HIGH);
  digitalWrite(rightBackward, LOW);
}

void reverse()
{
  /*The pin numbers and high, low values might be different depending on your connections */
  digitalWrite(leftForward, LOW);
  digitalWrite(leftBackward, HIGH);
  digitalWrite(rightForward, LOW);
  digitalWrite(rightBackward, HIGH);
}

void left()
{
  /*The pin numbers and high, low values might be different depending on your connections */
  digitalWrite(leftForward, LOW);
  digitalWrite(leftBackward, LOW);
  digitalWrite(rightForward, HIGH);
  digitalWrite(rightBackward, LOW);
}

void right()
{
  /*The pin numbers and high, low values might be different depending on your connections */
  digitalWrite(leftForward, HIGH);
  digitalWrite(leftBackward, LOW);
  digitalWrite(rightForward, LOW);
  digitalWrite(rightBackward, LOW);
}

void sharpLeftTurn() {
  /*The pin numbers and high, low values might be different depending on your connections */
  digitalWrite(leftForward, LOW);
  digitalWrite(leftBackward, HIGH);
  digitalWrite(rightForward, HIGH);
  digitalWrite(rightBackward, LOW);
}

void sharpRightTurn() {
  /*The pin numbers and high, low values might be different depending on your connections */
  digitalWrite(leftForward, HIGH);
  digitalWrite(leftBackward, LOW);
  digitalWrite(rightForward, LOW);
  digitalWrite(rightBackward, HIGH);
}

void stop_bot()
{
  /*The pin numbers and high, low values might be different depending on your connections */
  digitalWrite(leftForward, LOW);
  digitalWrite(leftBackward, LOW);
  digitalWrite(rightForward, LOW);
  digitalWrite(rightBackward, LOW);
}

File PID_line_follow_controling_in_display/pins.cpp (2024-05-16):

#include "pins.h"

// Define motor pins
const int leftmotor_pwm = 9;
const int rightmotor_pwm = 8;
const int leftForward = 26;
const int rightForward = 22;
const int leftBackward = 28;
const int rightBackward = 24;

//Define encoder pins
const int ENCA = 2; // YELLOW
const int ENCB = 3; // WHITE

// Define IR sensor pins
const int sensorPins[numSensors] = {A7, A6, A15, A14, A13, A12, A11, A10, A9, A8, A5, A4};


//display,
const int SCREEN_WIDTH = 128;
const int SCREEN_HEIGHT = 64;
const int OLED_RESET = -1;

const int outputA =30 ;
const int outputB = 32;
const int btn = 34 ;

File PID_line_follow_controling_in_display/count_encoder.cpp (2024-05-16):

#include "count_encoder.h"

// Define the variables with static keyword to limit their scope to this translation unit
static int motor_pos;
static long motor_prevT = 0;
static float motor_eprev = 0;
static float motor_eintegral = 0;
static float motor_kp = 1;
static float motor_kd = 0.025;
static float motor_ki = 0.0;

// If you want to provide accessors to these variables, you can define them here as well.


void count_encoder(float rpe_count )
{
  motor_pos = 0;
  do{
  float target_approx = rpe * rpe_count - 5;
  if (motor_pos >= target_approx && target_approx > 0)
  {
    // Stop the motors
    setMotor(0, 0, leftmotor_pwm, rightmotor_pwm, leftBackward, leftForward, rightBackward, rightForward);
    // Break the loop
    return ;
  }
  if (motor_pos < target_approx && target_approx < 0)
  {
    // Stop the motors
    setMotor(0, 0, leftmotor_pwm, rightmotor_pwm, leftBackward, leftForward, rightBackward, rightForward);
    // Break the loop
    return;
  }

  // time difference
  long currT = micros();
  float deltaT = ((float)(currT - motor_prevT)) / (1.0e6);
  motor_prevT = currT;

  // error
  int e = motor_pos - rpe * rpe_count;

  // derivative
  float dedt = (e - motor_eprev) / (deltaT);

  // integral
  motor_eintegral = motor_eintegral + e * deltaT;

  // control signal
  float u = motor_kp * e + motor_kd * dedt + motor_ki * motor_eintegral;

  // motor power
  float pwr = fabs(u);
  if (pwr > 75)
  {
    pwr = 75;
  }
  else if (pwr < 30)
  { // Add this condition to limit pwr above 30
    pwr = 30;
  }

  // motor direction
  int dir = 1;
  if (u < 0)
  {
    dir = -1;
  }

  // signal the motors
  setMotor(dir, pwr, leftmotor_pwm, rightmotor_pwm, leftBackward, leftForward, rightBackward, rightForward);

  // store previous error
  motor_eprev = e;
  Serial.println("1000");
  } while (!((motor_pos >= target_approx && target_approx > 0) || (motor_pos < target_approx && target_approx < 0)));
}

void setMotor(int dir, int pwmVal, int pwm, int pwm2, int in1, int in2, int in3, int in4)
{
  analogWrite(pwm, pwmVal);
  analogWrite(pwm2, pwmVal);
  if (dir == 1)
  {
    digitalWrite(in1, HIGH);
    digitalWrite(in2, LOW);
    digitalWrite(in3, HIGH);
    digitalWrite(in4, LOW);
  }
  else if (dir == -1)
  {
    digitalWrite(in1, LOW);
    digitalWrite(in2, HIGH);
    digitalWrite(in3, LOW);
    digitalWrite(in4, HIGH);
  }
  else
  {
    digitalWrite(in1, LOW);
    digitalWrite(in2, LOW);
    digitalWrite(in3, LOW);
    digitalWrite(in4, LOW);
  }
}

void readEncoder()
{
  int b = digitalRead(ENCB);
  if (b > 0)
  {
    motor_pos++;
  }
  else
  {
    motor_pos--;
  }
}

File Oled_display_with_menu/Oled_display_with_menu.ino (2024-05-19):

#include <Wire.h>
#include <Adafruit_GFX.h>
#include <Adafruit_SSD1306.h>

#define SCREEN_WIDTH 128
#define SCREEN_HEIGHT 64
#define OLED_RESET -1

#define outputA 30
#define outputB 32
#define btn 34

Adafruit_SSD1306 display(SCREEN_WIDTH, SCREEN_HEIGHT, &Wire, OLED_RESET);

int counter = 1;
int aState;
int aLastState;
bool btnPressed = false;
unsigned long lastButtonPressTime = 0;
const unsigned long doublePressDelay = 500; // Adjust this as needed

enum MenuState {
  MAIN_MENU,
  CALIBRATION_MENU,
  CALIBRATION_START,
  CALIBRATION_SAVE,
  PID_MENU,
  ARM,
  PID_KP,
  PID_KD,
  PID_KI
};

MenuState currentMenu = MAIN_MENU;
MenuState mainMenuPrevious = MAIN_MENU;
MenuState calibrationMenuPrevious = MAIN_MENU;
MenuState pidMenuPrevious = MAIN_MENU;

void setup() {
  pinMode (outputA, INPUT);
  pinMode (outputB, INPUT);
  pinMode(btn, INPUT_PULLUP);

  Serial.begin(9600);
  aLastState = digitalRead(outputA);
  display.begin(SSD1306_SWITCHCAPVCC, 0x3C);
  display.clearDisplay();
}

void loop() {

  int btnState = digitalRead(btn);
  unsigned long currentTime = millis();

  if (btnState == LOW && !btnPressed) {
    if (currentTime - lastButtonPressTime < doublePressDelay) {
      returnToPreviousMenu();
    } else {
      btnPressed = true;
      lastButtonPressTime = currentTime;
      delay(100); // Debounce delay
      handleMenuSelection(counter);
    }
  } else if (btnState == HIGH) {
    btnPressed = false;
  }

  aState = digitalRead(outputA);
  if (aState != aLastState) {
    if (digitalRead(outputB) != aState) {
      counter++;
    } else {
      counter--;
    }
    if (currentMenu == MAIN_MENU) {
      if (counter < 1) counter = 1;
      if (counter > 3) counter = 3;
    } else if (currentMenu == CALIBRATION_MENU) {
      if (counter < 1) counter = 1;
      if (counter > 2) counter = 2;
    } else if (currentMenu == PID_MENU) {
      if (counter < 1) counter = 1;
      if (counter > 3) counter = 3;
    }
    Serial.print("Position: ");
    Serial.println(counter);
  }
  aLastState = aState;

  display.setTextColor(SSD1306_WHITE);
  display.clearDisplay();

  switch (currentMenu) {
    case MAIN_MENU:
      displayMainMenu();
      break;
    case CALIBRATION_MENU:
      displayCalibrationMenu();
      break;
    case CALIBRATION_START:
      display.setTextSize(1);
      display.setCursor(0, 0);
      display.println("Calibration: Start");
      // Add your code for "Start" calibration here
      Serial.println("start");
      break;
    case CALIBRATION_SAVE:
      display.setTextSize(1);
      display.setCursor(0, 0);
      display.println("Calibration: Save to EEPROM");
      // Add your code for "Save to EEPROM" calibration here
      break;
    case PID_MENU:
      displayPIDMenu();
      break;
    case PID_KP:
      display.setTextSize(1);
      display.setCursor(0, 0);
      display.println("PID: KP");
      // Add your code for PID control here
      break;
    case PID_KD:
      display.setTextSize(1);
      display.setCursor(0, 0);
      display.println("PID: KD");
      // Add your code for PID control here
      break;
    case PID_KI:
      display.setTextSize(1);
      display.setCursor(0, 0);
      display.println("PID: KI");
      // Add your code for PID control here
      break;
    case ARM:
      display.setTextSize(1);
      display.setCursor(0, 0);
      display.println("ARM");
      // Add your code for ARM control here
      break;
  }

  display.display();
}

void displayMainMenu() {
  int textWidth = 12 * 5;
  int x = (SCREEN_WIDTH - textWidth) / 2;
  display.setTextSize(2);
  display.setCursor(x, 0);
  display.println("GOLEM");

  display.setTextSize(1);
  display.setCursor(20, 25);
  if (counter == 1) {
    display.setTextColor(SSD1306_BLACK, SSD1306_WHITE); // Highlight selected item
  } else {
    display.setTextColor(SSD1306_WHITE);
  }
  display.println("1. Calibration");
  display.setTextColor(SSD1306_WHITE); // Reset color
  display.setCursor(20, 35);
  if (counter == 2) {
    display.setTextColor(SSD1306_BLACK, SSD1306_WHITE); // Highlight selected item
  } else {
    display.setTextColor(SSD1306_WHITE);
  }
  display.println("2. PID Control");
  display.setTextColor(SSD1306_WHITE); // Reset color
  display.setCursor(20, 45);
  if (counter == 3) {
    display.setTextColor(SSD1306_BLACK, SSD1306_WHITE); // Highlight selected item
  } else {
    display.setTextColor(SSD1306_WHITE);
  }
  display.println("3. ARM");
}

void displayCalibrationMenu() {
  int textWidth = 6 * 11;
  int x = (SCREEN_WIDTH - textWidth) / 2;
  display.setTextSize(1);
  display.setCursor(x, 0);
  display.println("CALIBRATION");

  display.setTextSize(1);
  display.setCursor(20, 25);
  if (counter == 1) {
    display.setTextColor(SSD1306_BLACK, SSD1306_WHITE); // Highlight selected item
  } else {
    display.setTextColor(SSD1306_WHITE);
  }
  display.println("1. Start");
  display.setTextColor(SSD1306_WHITE); // Reset color
  display.setCursor(20, 35);
  if (counter == 2) {
    display.setTextColor(SSD1306_BLACK, SSD1306_WHITE); // Highlight selected item
  } else {
    display.setTextColor(SSD1306_WHITE);
  }
  display.println("2. Save to EEPROM");
}

void displayPIDMenu() {
  int textWidth = 6 * 11;
  int x = (SCREEN_WIDTH - textWidth) / 2;
  display.setTextSize(1);
  display.setCursor(x, 0);
  display.println("PID CONTROL");

  display.setTextSize(1);
  display.setCursor(20, 25);
  if (counter == 1) {
    display.setTextColor(SSD1306_BLACK, SSD1306_WHITE); // Highlight selected item
  } else {
    display.setTextColor(SSD1306_WHITE);
  }
  display.println("1. KP");
  display.setTextColor(SSD1306_WHITE); // Reset color
  display.setCursor(20, 35);
  if (counter == 2) {
    display.setTextColor(SSD1306_BLACK, SSD1306_WHITE); // Highlight selected item
  } else {
    display.setTextColor(SSD1306_WHITE);
  }
  display.println("2. KD");
  display.setTextColor(SSD1306_WHITE); // Reset color
  display.setCursor(20, 45);
  if (counter == 3) {
    display.setTextColor(SSD1306_BLACK, SSD1306_WHITE); // Highlight selected item
  } else {
    display.setTextColor(SSD1306_WHITE);
  }
  display.println("3. KI");
}
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

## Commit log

2024-05-11 This is 3d printed parts that I printed using my imagineer 3d printed
    [20x20x1kosebent.SLDPRT, Arm assemble.SLDASM, Arm handle large.SLDPRT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]
2024-05-11 3d printed parts for tof holder
    [TCS34725_RGB_sensor_HOLDER.SLDPRT, TCS34725_RGB_sensor_HOLDER.STL, Tof_sensor_holder.SLDPRT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]
2024-05-12 Elimination round code
    This is elimination round code that I run in Arduino mega-2560 board.
2024-05-13 SLRC shield
    This is a shield that I designed for SLRC.
    [Arduino mega shield.PcbDoc, Arduino mega shield.SchDoc, Block Diagram.SchDoc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]
2024-05-13 Two encoder motors & ultrasonic sensor codes
    This is a code that I used to get the ultrasonic sensor values to array and two encoder motors
2024-05-13 TCS34725 RGB sensor
    Get RGB values using TCS34725 RGB sensor
2024-05-13 TOF VL53l0 sensor
    Get readings using TOF VL53l0 sensor
2024-05-14 Reverse Ir array
    This code is use to get values from reverse IR array. It use Analog multiplexer CD74HC4067.
    [reverse_ir_array.ino]
2024-05-14 Rotaty encoder
    This is the code for rotary encoder with btn
2024-05-14 Servo grab and hold
    This is simple 2 dof servo arm controller code
2024-05-14 Variance and stranded deviation calculate
    This code is use to calculate variance and stranded deviation using ultrasonic sensor.
2024-05-16 After adding reverse ir array
    After passing elimination round i add 6 IR array for back side of the robot. In this code I add reverse IR array calibration part.
    [PID_line_follow_controling_v8_calibration_reverse.ino, calibrate_sensor.cpp, color_sensor.cpp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]
2024-05-16 After motor change
    Before the elimination round 78rpm motor was broken. Since I had not any 78rmp motor I add 200rpm motor. This is the code for After adding 200rpm motor.
    [PID_line_follow_with200rpm_and_78_rpm.ino, calibrate_sensor.cpp, line_follow.cpp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]
2024-05-16 After adding oled display
    This is the code after adding oled display. This oled display have function for calibration, saving calibration values to eeprom , PID value change and run the code(go).
2024-05-19 Simple motor testing code
2024-05-19 Motor testing 200rpm and 70 rpm
2024-05-20 IR calibration codoe
    This is Ir sensor analog value calibration code
2024-05-20 Read Ir sensor values
    This is a simple code for reading values from ir sensors.
2024-05-20 Angle messure using MPU6050
    This is a code for get angle form the gyroscope.
